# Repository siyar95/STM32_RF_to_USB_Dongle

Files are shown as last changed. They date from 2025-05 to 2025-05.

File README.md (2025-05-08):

# RF to USB Dongle – STM32L432 + nRF24L01

This project is a compact **RF-to-USB dongle** built using an **STM32L432KBU** microcontroller and an **nRF24L01** 2.4 GHz transceiver module.  
The device receives RF data wirelessly and transmits it to a host computer over USB.

## 🔧 Features

- **MCU**: STM32L432KBU (ARM Cortex-M4, ultra-low power)
- **RF Module**: nRF24L01 (2.4 GHz transceiver)
- **USB Interface**: Native USB device for communication with PC or host
- **SPI Interface**: Used to communicate with the nRF24L01
- **Low Power Operation**: Suitable for battery-powered wireless systems
- **Compact Design**: USB dongle-style form factor

## 🎯 Applications

- Wireless data receiver (e.g., for sensors, remotes)
- USB dongle for custom RF communication protocols
- PC bridge for STM32-based RF networks
- Debugging/logging tool for embedded wireless systems

## 🧱 PCB Details

- 4-layer PCB
- **Micro-USB (Type B)** connector
- On-board 3.3V LDO regulator for nRF24L01 and STM32
- SMA antenna

## 🧱 PCB Stackup

This project uses a 4-layer PCB for better signal integrity and power distribution:

1. **Top Layer (Layer 1)** – Signal  
2. **Inner Layer 1 (Layer 2)** – Ground (GND)  
3. **Inner Layer 2 (Layer 3)** – 3.3V Power Plane  
4. **Bottom Layer (Layer 4)** – Signal








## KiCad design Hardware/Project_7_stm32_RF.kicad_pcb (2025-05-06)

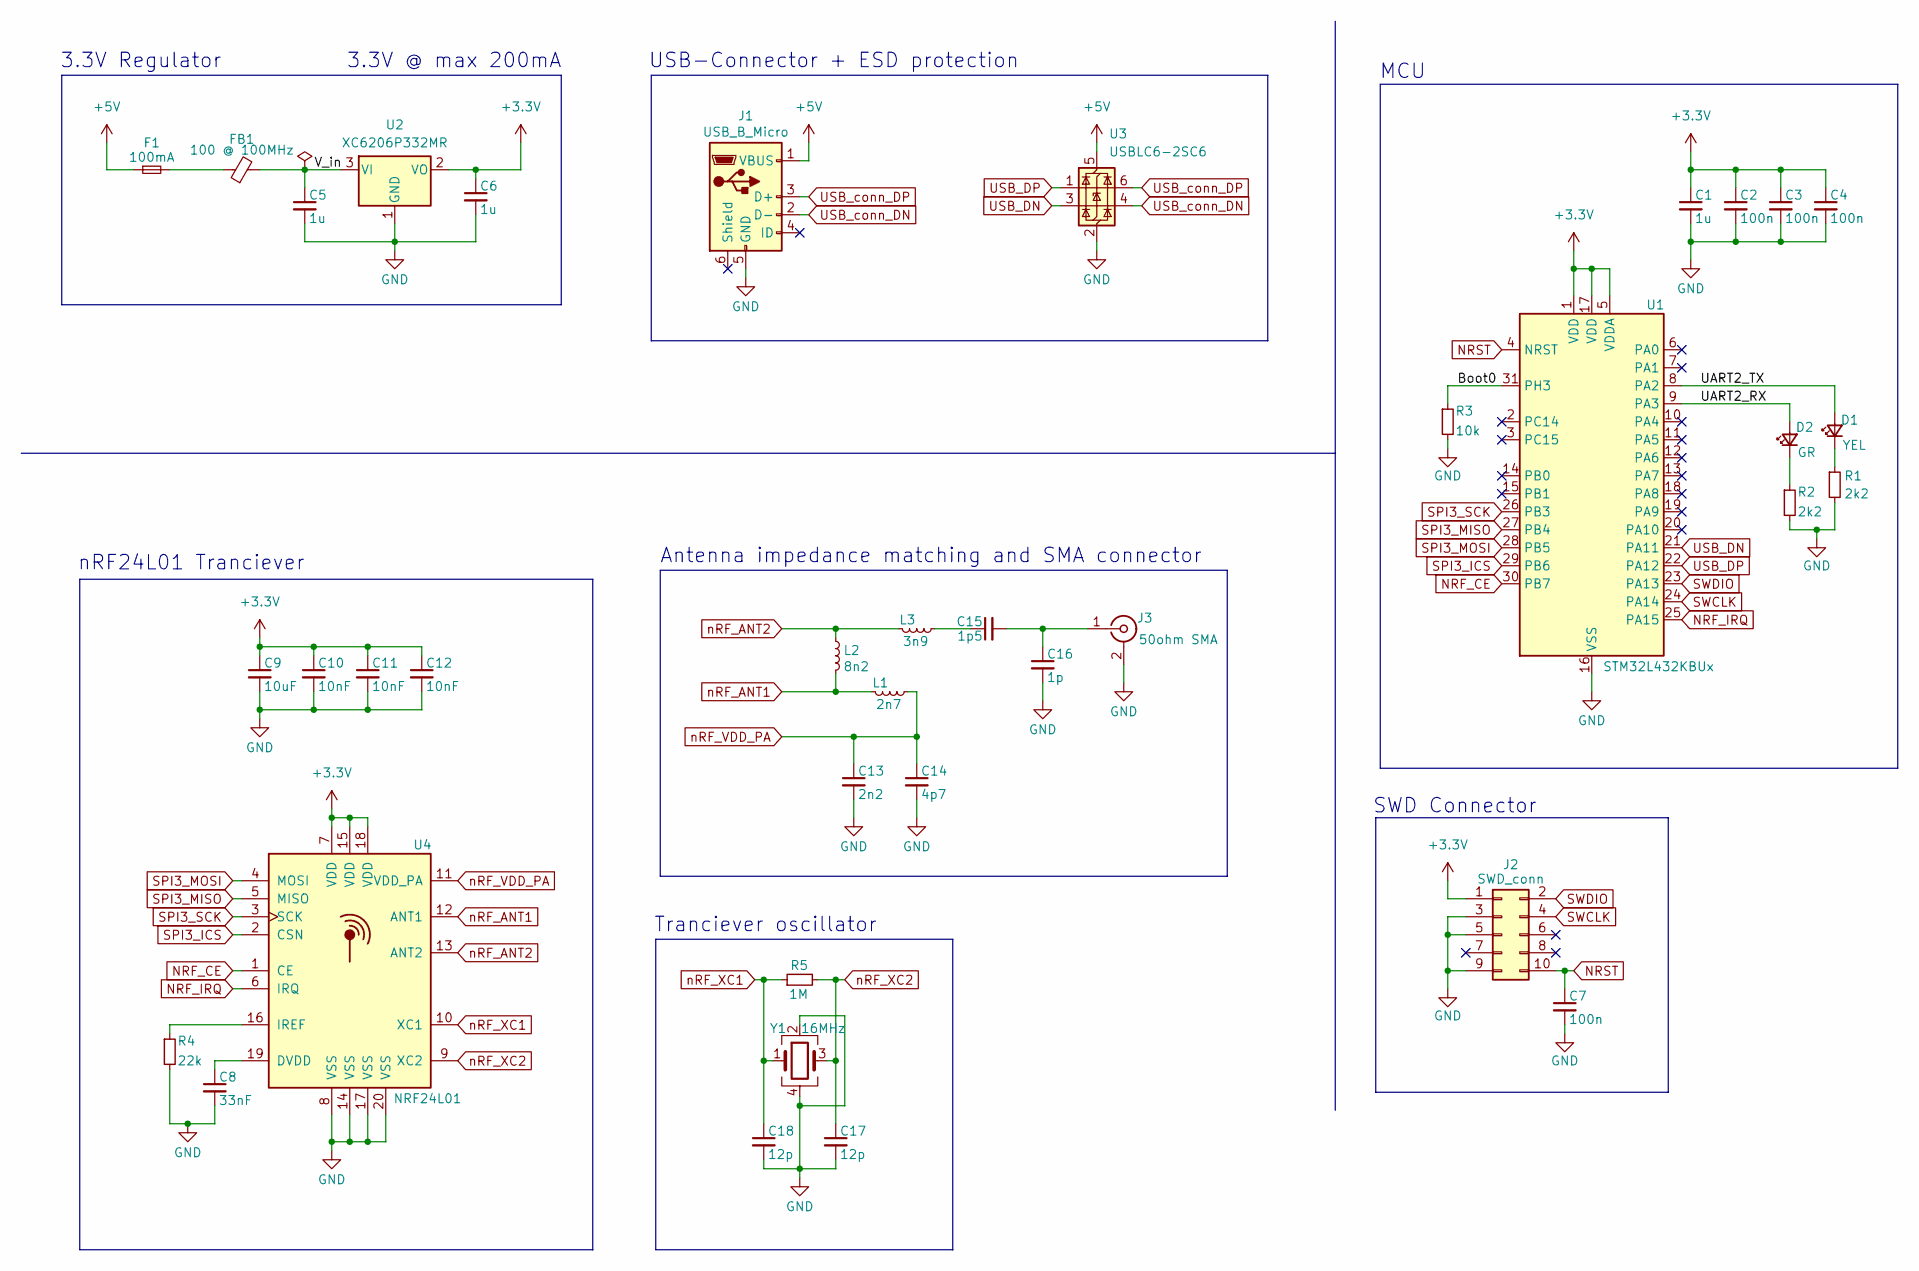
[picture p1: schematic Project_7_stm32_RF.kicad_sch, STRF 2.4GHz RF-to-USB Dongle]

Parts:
C1: 1u; C_0402_1005Metric
C2, C3, C4, C7: 100n; C_0402_1005Metric
C5, C6: 1u; C_0603_1608Metric
C8: 33nF; C_0402_1005Metric
C9: 10uF; C_0402_1005Metric
C10, C11, C12: 10nF; C_0402_1005Metric
C13: 2n2; C_0402_1005Metric
C14: 4p7; C_0402_1005Metric
C15: 1p5; C_0402_1005Metric
C16: 1p; C_0402_1005Metric
C17, C18: 12p; C_0402_1005Metric
D1: YEL; LED_0603_1608Metric
D2: GR; LED_0603_1608Metric
F1: 100mA; Fuse_1206_3216Metric
FB1: 100 @ 100MHz; L_0805_2012Metric
J1: USB_B_Micro; USB_Micro-B_Molex-105017-0001
J2: SWD_conn; PinHeader_2x05_P2.54mm_Vertical
J3: 50ohm SMA; SMA_Samtec_SMA-J-P-H-ST-EM1_EdgeMount
L1: 2n7; L_0402_1005Metric
L2: 8n2; L_0402_1005Metric
L3: 3n9; L_0402_1005Metric
R1, R2: 2k2; R_0603_1608Metric
R3: 10k; R_0402_1005Metric
R4: 22k; R_0402_1005Metric
R5: 1M; R_0402_1005Metric
U1: STM32L432KBUx; QFN-32-1EP_5x5mm_P0.5mm_EP3.45x3.45mm
U2: XC6206P332MR; SOT-23-3
U3: USBLC6-2SC6; SOT-23-6
U4: NRF24L01; QFN-20-1EP_4x4mm_P0.5mm_EP2.5x2.5mm
Y1: 16MHz; Crystal_SMD_3225-4Pin_3.2x2.5mm

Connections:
+3.3V: C1.1, C2.1, C3.1, C4.1, C6.1, C9.1, C10.1, C11.1, C12.1, J2.1, U1.1 (VDD), U1.5 (VDDA), U1.17 (VDD), U2.2 (VO), U4.7 (VDD), U4.15 (VDD), U4.18 (VDD); also elsewhere on the board
+5V: F1.1, J1.1 (VBUS), U3.5 (VBUS)
/Boot0: R3.1, U1.31 (PH3)
/UART2_RX: D2.2 (A), U1.9 (PA3)
/UART2_TX: D1.2 (A), U1.8 (PA2)
/V_in: C5.1, FB1.2, U2.3 (VI)
GND: C1.2, C2.2, C3.2, C4.2, C5.2, C6.2, C7.2, C8.2, C9.2, C10.2, C11.2, C12.2, C13.2, C14.2, C16.2, C17.2, C18.2, J1.5 (GND), J2.3, J2.5, J2.9, J3.2 (Ext), R1.2, R2.2, R3.2, R4.2, U1.16 (VSS), U1.32 (VSS), U1.33 (VSS), U2.1 (GND), U3.2 (GND), U4.8 (VSS), U4.14 (VSS), U4.17 (VSS), U4.20 (VSS), Y1.2, Y1.4; also elsewhere on the board
NRF_CE: U1.30 (PB7), U4.1 (CE)
NRF_IRQ: U1.25 (PA15), U4.6 (IRQ)
NRST: C7.1, J2.10, U1.4 (NRST); also elsewhere on the board
unnamed: C15.1, L3.1
unnamed: D1.1 (K), R1.1
unnamed: D2.1 (K), R2.1
unnamed: F1.2, FB1.1
unnamed 14: C15.2, C16.1, J3.1 (In); also elsewhere on the board
unnamed: C8.1, U4.19 (DVDD)
unnamed: R4.1, U4.16 (IREF)
SPI3_ICS: U1.29 (PB6), U4.2 (CSN)
SPI3_MISO: U1.27 (PB4), U4.5 (MISO)
SPI3_MOSI: U1.28 (PB5), U4.4 (MOSI)
SPI3_SCK: U1.26 (PB3), U4.3 (SCK)
SWCLK: J2.4, U1.24 (PA14); also elsewhere on the board
SWDIO: J2.2, U1.23 (PA13); also elsewhere on the board
USB_DN: U1.21 (PA11), U3.3 (I/O2)
USB_DP: U1.22 (PA12), U3.1 (I/O1)
USB_conn_DN: J1.2 (D-), U3.4 (I/O2)
USB_conn_DP: J1.3 (D+), U3.6 (I/O1)
nRF_ANT1: L1.2, L2.2, U4.12 (ANT1)
nRF_ANT2: L2.1, L3.2, U4.13 (ANT2)
nRF_VDD_PA: C13.1, C14.1, L1.1, U4.11 (VDD_PA)
nRF_XC1: C18.1, R5.1, U4.10 (XC1), Y1.1
nRF_XC2: C17.1, R5.2, U4.9 (XC2), Y1.3

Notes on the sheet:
SWD Connector
Antenna impedance matching and SMA connector
3.3V Regulator
MCU
3.3V @ max 200mA
nRF24L01 Tranciever
Tranciever oscillator
USB-Connector + ESD protection

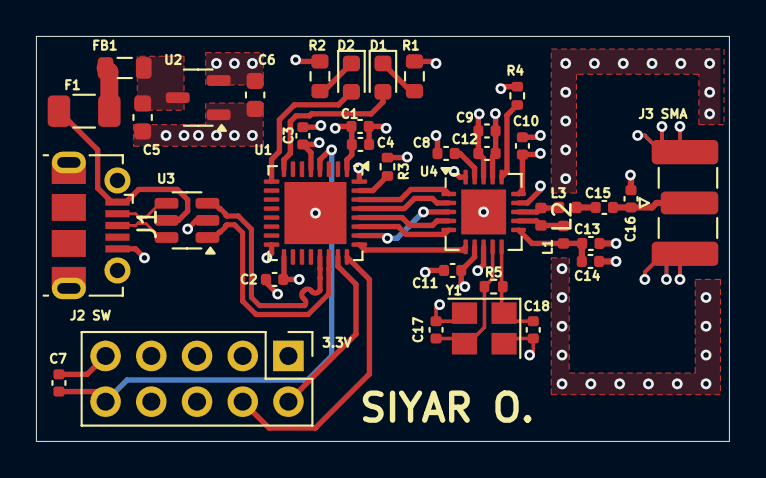
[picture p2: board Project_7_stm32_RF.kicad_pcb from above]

Board: 4 copper layers, 38.5 x 22.5 mm, 38 parts (0 on the bottom side), 32 nets.

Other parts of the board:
J2 SW: SWD_conn; PinHeader_2x05_P2.54mm_Vertical
J3 SMA: 50ohm SMA; SMA_Samtec_SMA-J-P-H-ST-EM1_EdgeMount

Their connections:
+3.3V: J2 SW.1; also elsewhere on the board
GND: J2 SW.3, J2 SW.5, J2 SW.9, J3 SMA.2 (Ext); also elsewhere on the board
NRST: J2 SW.10; also elsewhere on the board
unnamed 14: J3 SMA.1 (In); also elsewhere on the board
SWCLK: J2 SW.4; also elsewhere on the board
SWDIO: J2 SW.2; also elsewhere on the board

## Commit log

2025-05-06 Update and rename Project_7_stm32_RF.kicad_pcb to Hardware/Project_7_stm32_RF.kicad_pcb
    [Project_7_stm32_RF.kicad_pcb]
2025-05-06 Update and rename Project_7_stm32_RF.kicad_sch to Hardware/Project_7_stm32_RF.kicad_sch
    [Project_7_stm32_RF.kicad_sch]
